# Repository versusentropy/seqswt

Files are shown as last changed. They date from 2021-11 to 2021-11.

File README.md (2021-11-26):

# seqswt eurorack 4(3,2) to 1 sequential switch

## v0.9

Known bug: Label 2 and 3 at the switch are reversed.

  * 4hp
  * +/-12V 10mA/1mA
  * 1 PCB 2 layer
  * common jack is connected to one output at a time
    * DG412 Rail2Rail analog switch recommended
  * step input
    * move to next position
    * TN pin header on pcb
  * reset input
    * move to step 1
    * locked on step 1, while gate high.
<!--<img align="right" src="doc/pcb.jpg" alt="pcb" width="75vh"/>-->
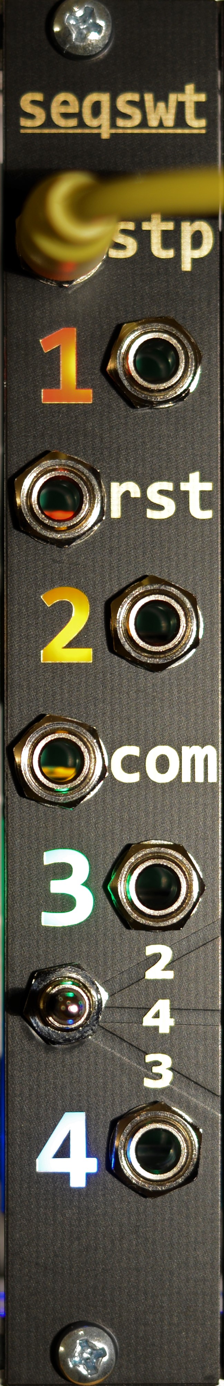
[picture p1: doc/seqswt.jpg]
panel

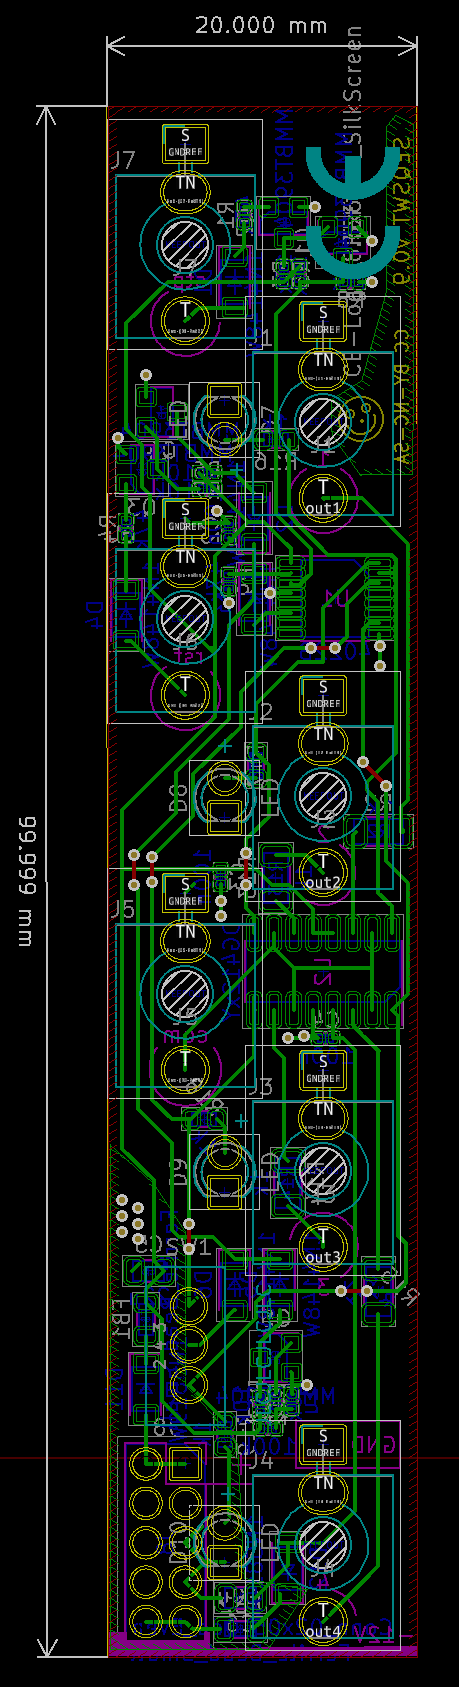
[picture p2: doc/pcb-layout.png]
pcb


Schematic and layout with KiCad 5. Panel with Inkscape + shenzen2svg → Kicad

Ordered mine at JLCPCB. Added ICs by hand. Gerbers include marking for order number. BOM with part numbers for their assembly service.

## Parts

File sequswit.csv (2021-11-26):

Comment | Designator | Footprint | LCSC
1u | C1 | Capacitor_SMD:C_0402_1005Metric | C52923
100n | C2,C3,C4 | Capacitor_SMD:C_0402_1005Metric | C1525
22u | C5 | Capacitor_SMD:C_0805_2012Metric | C45783
10u | C6 | Capacitor_SMD:C_0805_2012Metric | C15850
1N4148W | D1,D2,D3,D4,D5,D6 | Diode_SMD:D_SOD-123 | C81598
1N5819W | D11,D12 | Diode_SMD:D_SOD-123 | C402219
Ferrite_Bead_Small | FB1,FB2 | Inductor_SMD:L_0805_2012Metric | C1017
MMBT3904 | Q1,Q2,Q3,Q4,Q5 | Package_TO_SOT_SMD:SOT-23 | C20526
47k | R1,R4,R8,R9 | Resistor_SMD:R_0402_1005Metric | C25792
100k | R10 | Resistor_SMD:R_0402_1005Metric | C25741
1k | R16,R17,R18,R19 | Resistor_SMD:R_0603_1608Metric | C21190
1k | R2,R13,R14,R15 | Resistor_SMD:R_1206_3216Metric | C4410
10k | R3,R5,R6,R7,R11,R12 | Resistor_SMD:R_0402_1005Metric | C25744
4022B | U1 | Package_SO:TSSOP-16_4.4x5mm_P0.65mm
DG412xY | U2 | Package_SO:SOIC-16_3.9x9.9mm_P1.27mm
Conn_02x05_Odd_Even | J8 | Connector_PinHeader_2.54mm:PinHeader_2x05_P2.54mm_Vertical
LED | D7,D8,D9,D10 | LED_THT:LED_D3.0mm
2 4 3 | SW1 | myKicadLib:SW_SPDT_2_5mm
1 | J1 | kicad_jacks:Jack_3.5mm_QingPu_WQP-PJ398SM_Vertical_CircularHolesSMALL
2 | J2 | kicad_jacks:Jack_3.5mm_QingPu_WQP-PJ398SM_Vertical_CircularHolesSMALL
3 | J3 | kicad_jacks:Jack_3.5mm_QingPu_WQP-PJ398SM_Vertical_CircularHolesSMALL
4 | J4 | kicad_jacks:Jack_3.5mm_QingPu_WQP-PJ398SM_Vertical_CircularHolesSMALL

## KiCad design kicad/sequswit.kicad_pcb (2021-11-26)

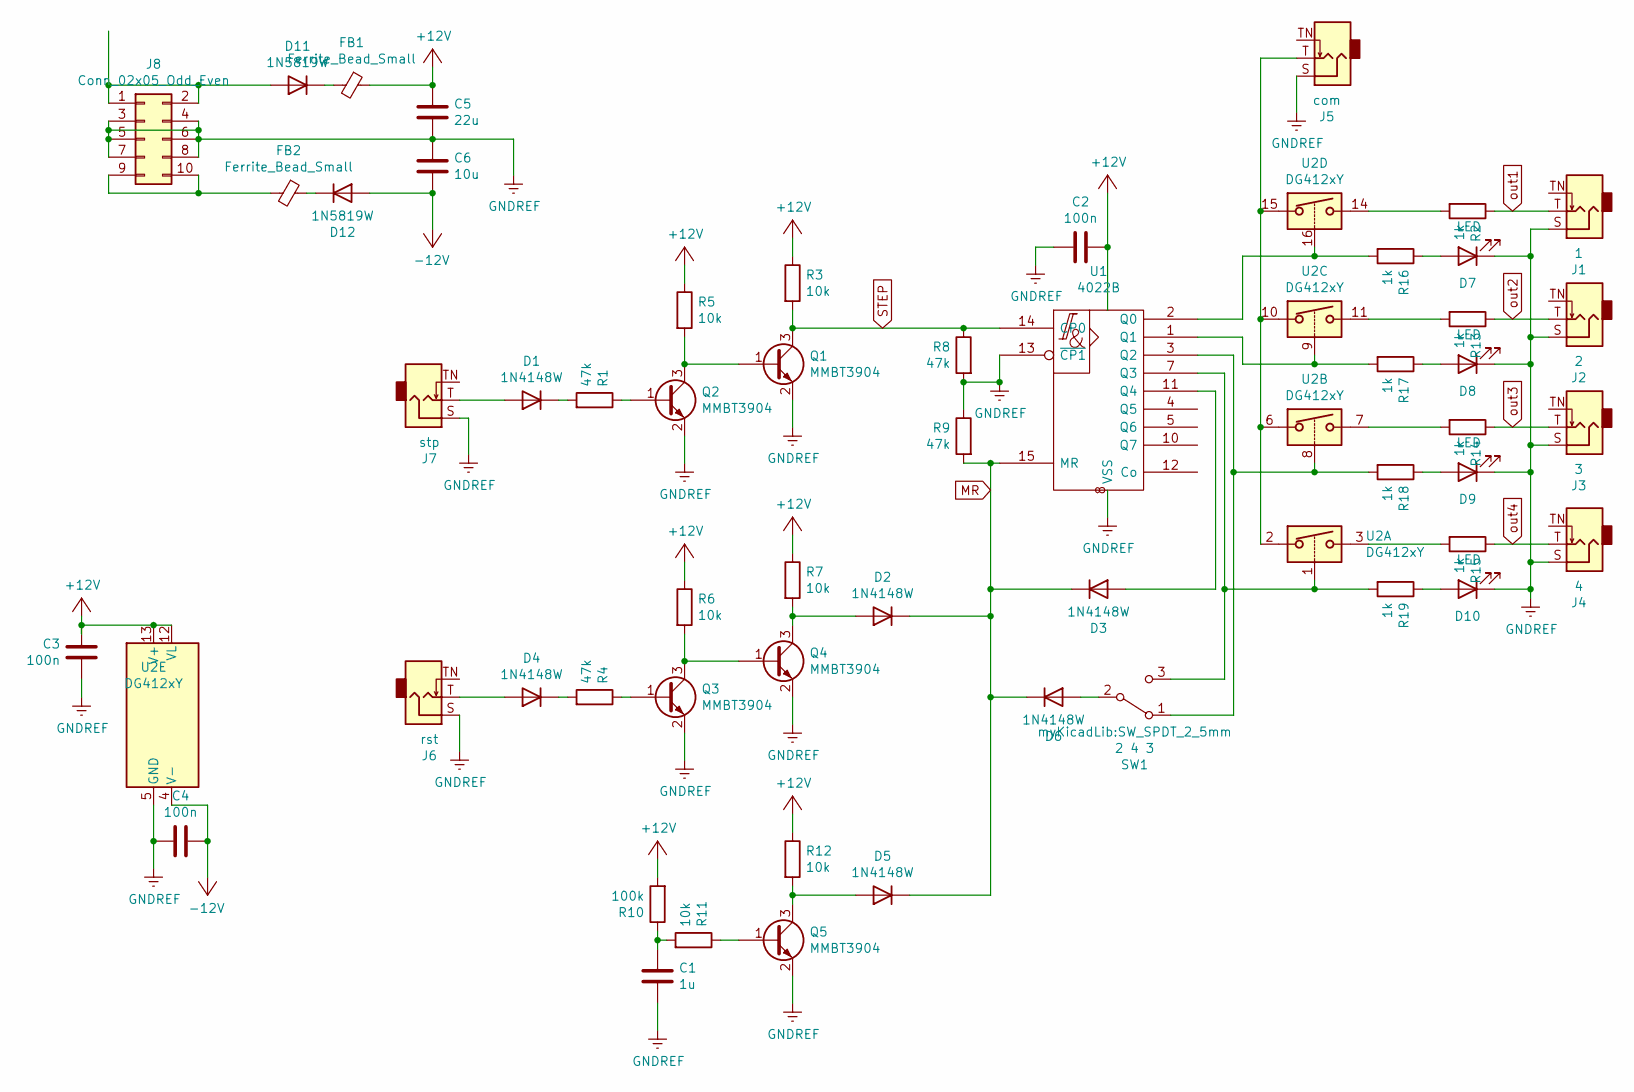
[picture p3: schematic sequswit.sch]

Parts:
C1: 1u; C_0402_1005Metric; LCSC C52923
C2, C3, C4: 100n; C_0402_1005Metric; LCSC C1525
C5: 22u; C_0805_2012Metric; LCSC C45783
C6: 10u; C_0805_2012Metric; LCSC C15850
D1, D2, D3, D4, D5, D6: 1N4148W; D_SOD-123; LCSC C81598
D7, D8, D9, D10: LED; LED_D3.0mm
D11, D12: 1N5819W; D_SOD-123; LCSC C402219
FB1, FB2: Ferrite_Bead_Small; L_0805_2012Metric; LCSC C1017
J1: 1; Jack_3.5mm_QingPu_WQP-PJ398SM_Vertical_CircularHolesSMALL
J2: 2; Jack_3.5mm_QingPu_WQP-PJ398SM_Vertical_CircularHolesSMALL
J3: 3; Jack_3.5mm_QingPu_WQP-PJ398SM_Vertical_CircularHolesSMALL
J4: 4; Jack_3.5mm_QingPu_WQP-PJ398SM_Vertical_CircularHolesSMALL
J5: com; Jack_3.5mm_QingPu_WQP-PJ398SM_Vertical_CircularHolesSMALL
J6: rst; Jack_3.5mm_QingPu_WQP-PJ398SM_Vertical_CircularHolesSMALL
J7: stp; Jack_3.5mm_QingPu_WQP-PJ398SM_Vertical_CircularHolesSMALL
J8: Conn_02x05_Odd_Even; PinHeader_2x05_P2.54mm_Vertical
Q1, Q2, Q3, Q4, Q5: MMBT3904; SOT-23; LCSC C20526
R1, R4, R8, R9: 47k; R_0402_1005Metric; LCSC C25792
R2, R13, R14, R15: 1k; R_1206_3216Metric; LCSC C4410
R3, R5, R6, R7, R11, R12: 10k; R_0402_1005Metric; LCSC C25744
R10: 100k; R_0402_1005Metric; LCSC C25741
R16, R17, R18, R19: 1k; R_0603_1608Metric; LCSC C21190
SW1: 2 4 3; SW_SPDT_2_5mm
U1: 4022B; TSSOP-16_4.4x5mm_P0.65mm; Mouser 595-CD4022BPWR
U2: DG412xY; SOIC-16_3.9x9.9mm_P1.27mm; Mouser 700-DG412DYT

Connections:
+12V: C2.2, C3.2, C5.1, FB1.1, R3.1, R5.1, R6.1, R7.1, R10.2, R12.1, U1.16 (VDD), U2.12 (VL), U2.13 (V+)
-12V: C4.1, C6.2, D12.2 (A), U2.4 (V-)
GNDREF: C1.1, C2.1, C3.1, C4.2, C5.2, C6.1, D7.1 (K), D8.1 (K), D9.1 (K), D10.1 (K), J1.S, J2.S, J3.S, J4.S, J5.S, J6.S, J7.S, J8.3, J8.4, J8.5, J8.6, J8.7, J8.8, Q1.2 (E), Q2.2 (E), Q3.2 (E), Q4.2 (E), Q5.2 (E), R8.2, R9.1, U1.8 (VSS), U1.13 (~CP1), U2.5 (GND)
MR: D2.1 (K), D3.1 (K), D5.1 (K), D6.1 (K), R9.2, U1.15 (MR)
unnamed: C1.2, R10.1, R11.2
unnamed: D1.1 (K), R1.2
unnamed: D1.2 (A), J7.T
unnamed: D2.2 (A), Q4.3 (C), R7.2
unnamed: D3.2 (A), U1.11 (Q4)
unnamed: D4.1 (K), R4.2
unnamed: D4.2 (A), J6.T
unnamed: D5.2 (A), Q5.3 (C), R12.2
unnamed: D6.2 (A), SW1.2 (B)
unnamed: D7.2 (A), R16.1
unnamed: D8.2 (A), R17.1
unnamed: D9.2 (A), R18.1
unnamed: D10.2 (A), R19.1
unnamed: D11.1 (K), FB1.2
unnamed: D11.2 (A), J8.1, J8.2
unnamed: D12.1 (K), FB2.1
unnamed: FB2.2, J8.9, J8.10
unnamed: J5.T, U2.2, U2.6, U2.10, U2.15
unnamed: Q1.1 (B), Q2.3 (C), R5.2
unnamed: Q2.1 (B), R1.1
unnamed: Q3.1 (B), R4.1
unnamed: Q3.3 (C), Q4.1 (B), R6.2
unnamed: Q5.1 (B), R11.1
unnamed: R2.2, U2.14
unnamed: R13.2, U2.11
unnamed: R14.2, U2.7
unnamed: R15.2, U2.3
unnamed: R16.2, U1.2 (Q0), U2.16
unnamed: R17.2, U1.1 (Q1), U2.9
unnamed: R18.2, SW1.1 (A), U1.3 (Q2), U2.8
unnamed: R19.2, SW1.3 (C), U1.7 (Q3), U2.1
STEP: Q1.3 (C), R3.2, R8.1, U1.14 (CP0)
out1: J1.T, R2.1
out2: J2.T, R13.1
out3: J3.T, R14.1
out4: J4.T, R15.1

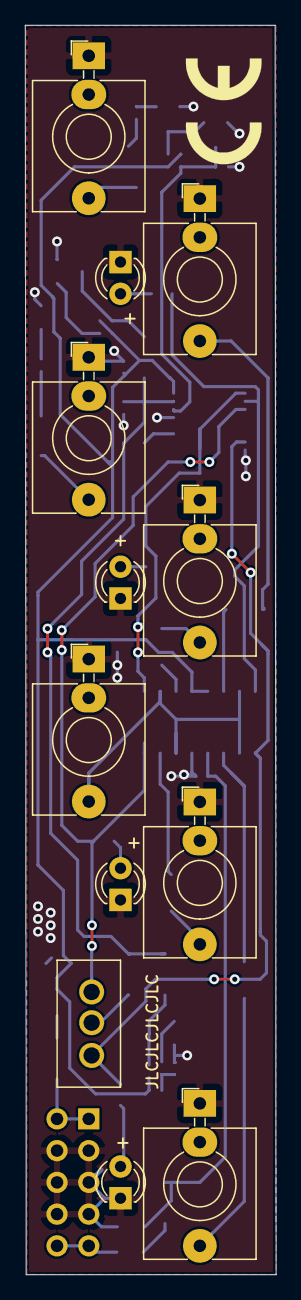
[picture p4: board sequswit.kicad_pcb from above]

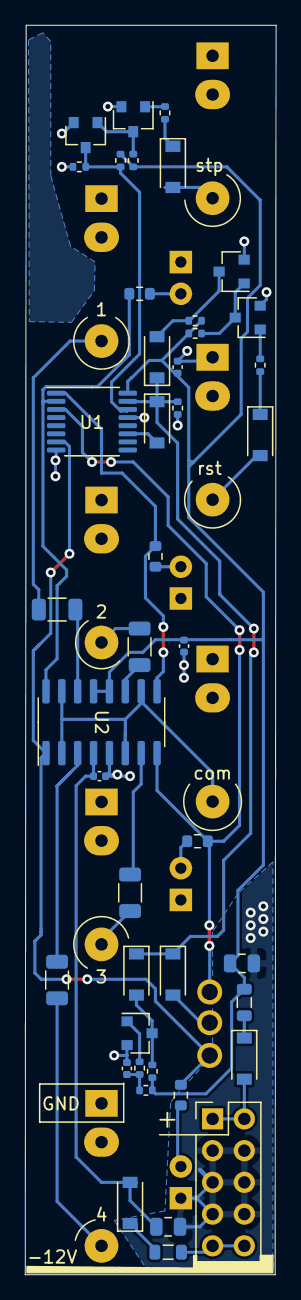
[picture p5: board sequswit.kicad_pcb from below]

Board: 2 copper layers, 20.1 x 100.0 mm, 55 parts (43 on the bottom side), 40 nets.

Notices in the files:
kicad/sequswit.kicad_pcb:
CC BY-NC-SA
